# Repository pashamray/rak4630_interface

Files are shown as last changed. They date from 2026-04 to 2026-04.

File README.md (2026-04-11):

# RAK4630 Interface

An open-source hardware breakout / interface board for the **RAK4630** LoRa module (Nordic nRF52840 + Semtech SX1262), designed in KiCad 9.

## Gallery

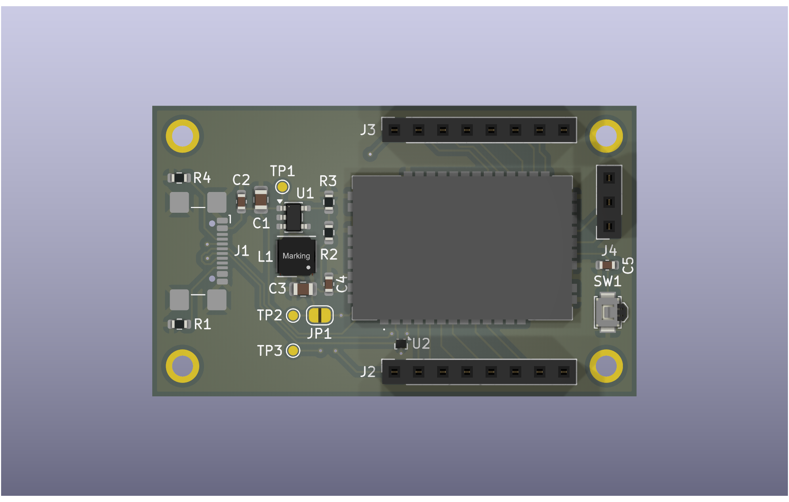
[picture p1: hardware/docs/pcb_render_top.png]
3D render top


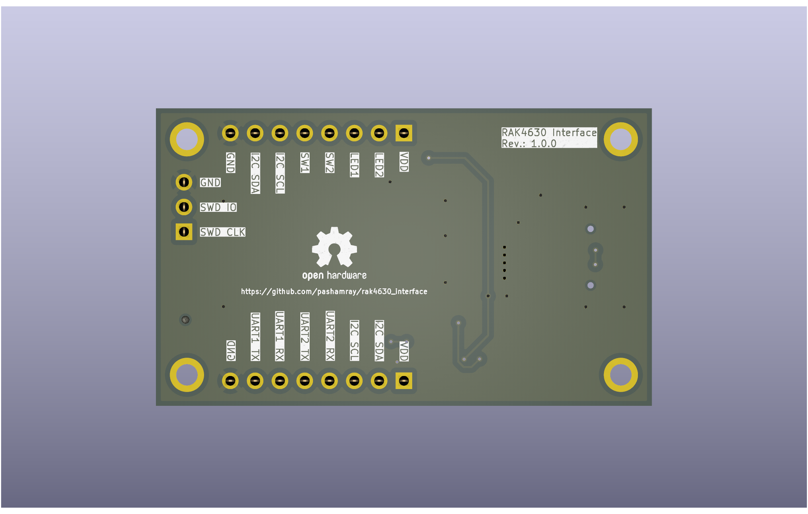
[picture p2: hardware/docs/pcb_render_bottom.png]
3D render bottom


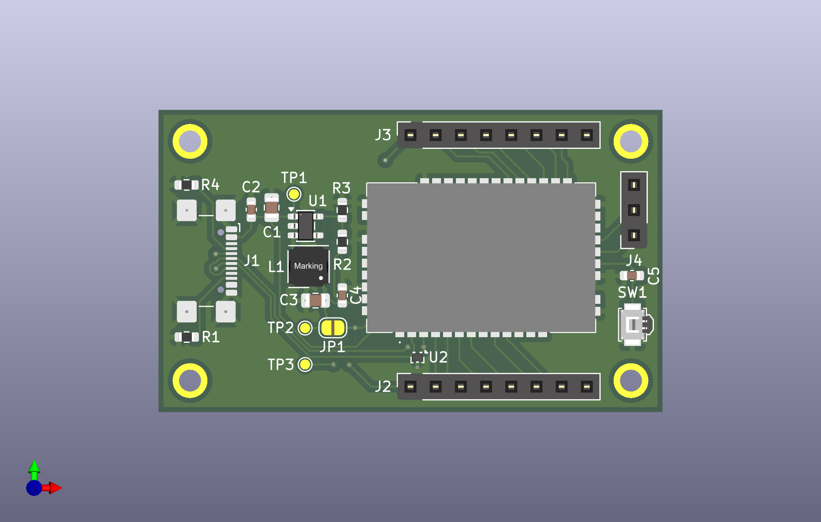
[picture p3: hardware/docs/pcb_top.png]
PCB top


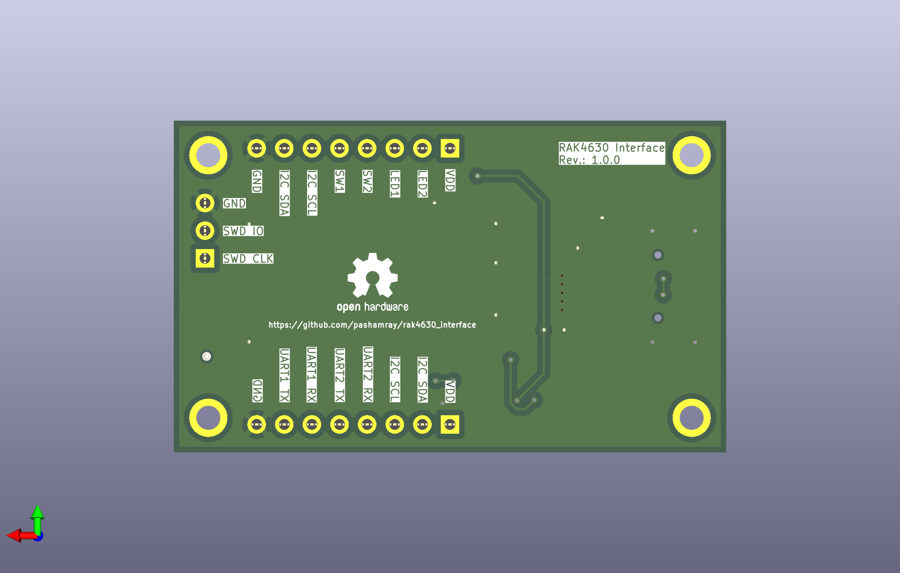
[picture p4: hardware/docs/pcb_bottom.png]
PCB bottom


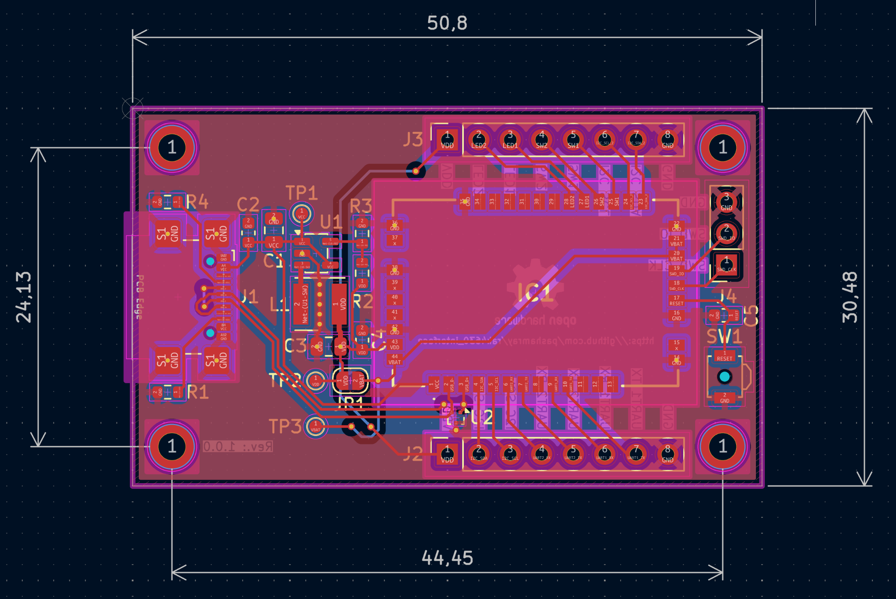
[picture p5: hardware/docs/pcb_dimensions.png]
PCB dimensions


## Overview

This board provides a minimal interface around the RAK4630 module, exposing its programming and I/O lines on a header and powering it from a USB-C port. It is intended as a development and flashing carrier for the RAK4630.

## Features

- **RAK4630 module** footprint (nRF52840 MCU + SX1262 LoRa radio)
- **USB-C 2.0 receptacle** for power and data
- **TPD2EUSB30** USB ESD protection
- **TLV62569DBV** step-down DC/DC converter for the 3.3 V rail
- **Reset push button**
- **Solder jumper** for power-rail / option configuration
- **8-pin breakout header** for GPIO / SWD / UART access
- **Test points** for key signals

## Repository layout

```
hardware/
├── kicad/      KiCad 9 project (schematic, PCB, project files)
├── gerber/     Manufacturing outputs (Gerbers + drill files)
└── libs/       Project-specific symbol/footprint/3D libraries (RAK4630)
```

## Manufacturing

Ready-to-fab Gerber and Excellon drill files are provided in `hardware/gerber/`. They follow the standard KiCad naming convention and can be uploaded as-is to most PCB fabrication houses.

## Opening the design

1. Install [KiCad 9](https://www.kicad.org/) or newer.
2. Open `hardware/kicad/rak4630_interface.kicad_pro`.

The RAK4630 symbol, footprint and 3D model are bundled under `hardware/libs/RAK4630/` and are referenced via the project library table — no global library setup is required.

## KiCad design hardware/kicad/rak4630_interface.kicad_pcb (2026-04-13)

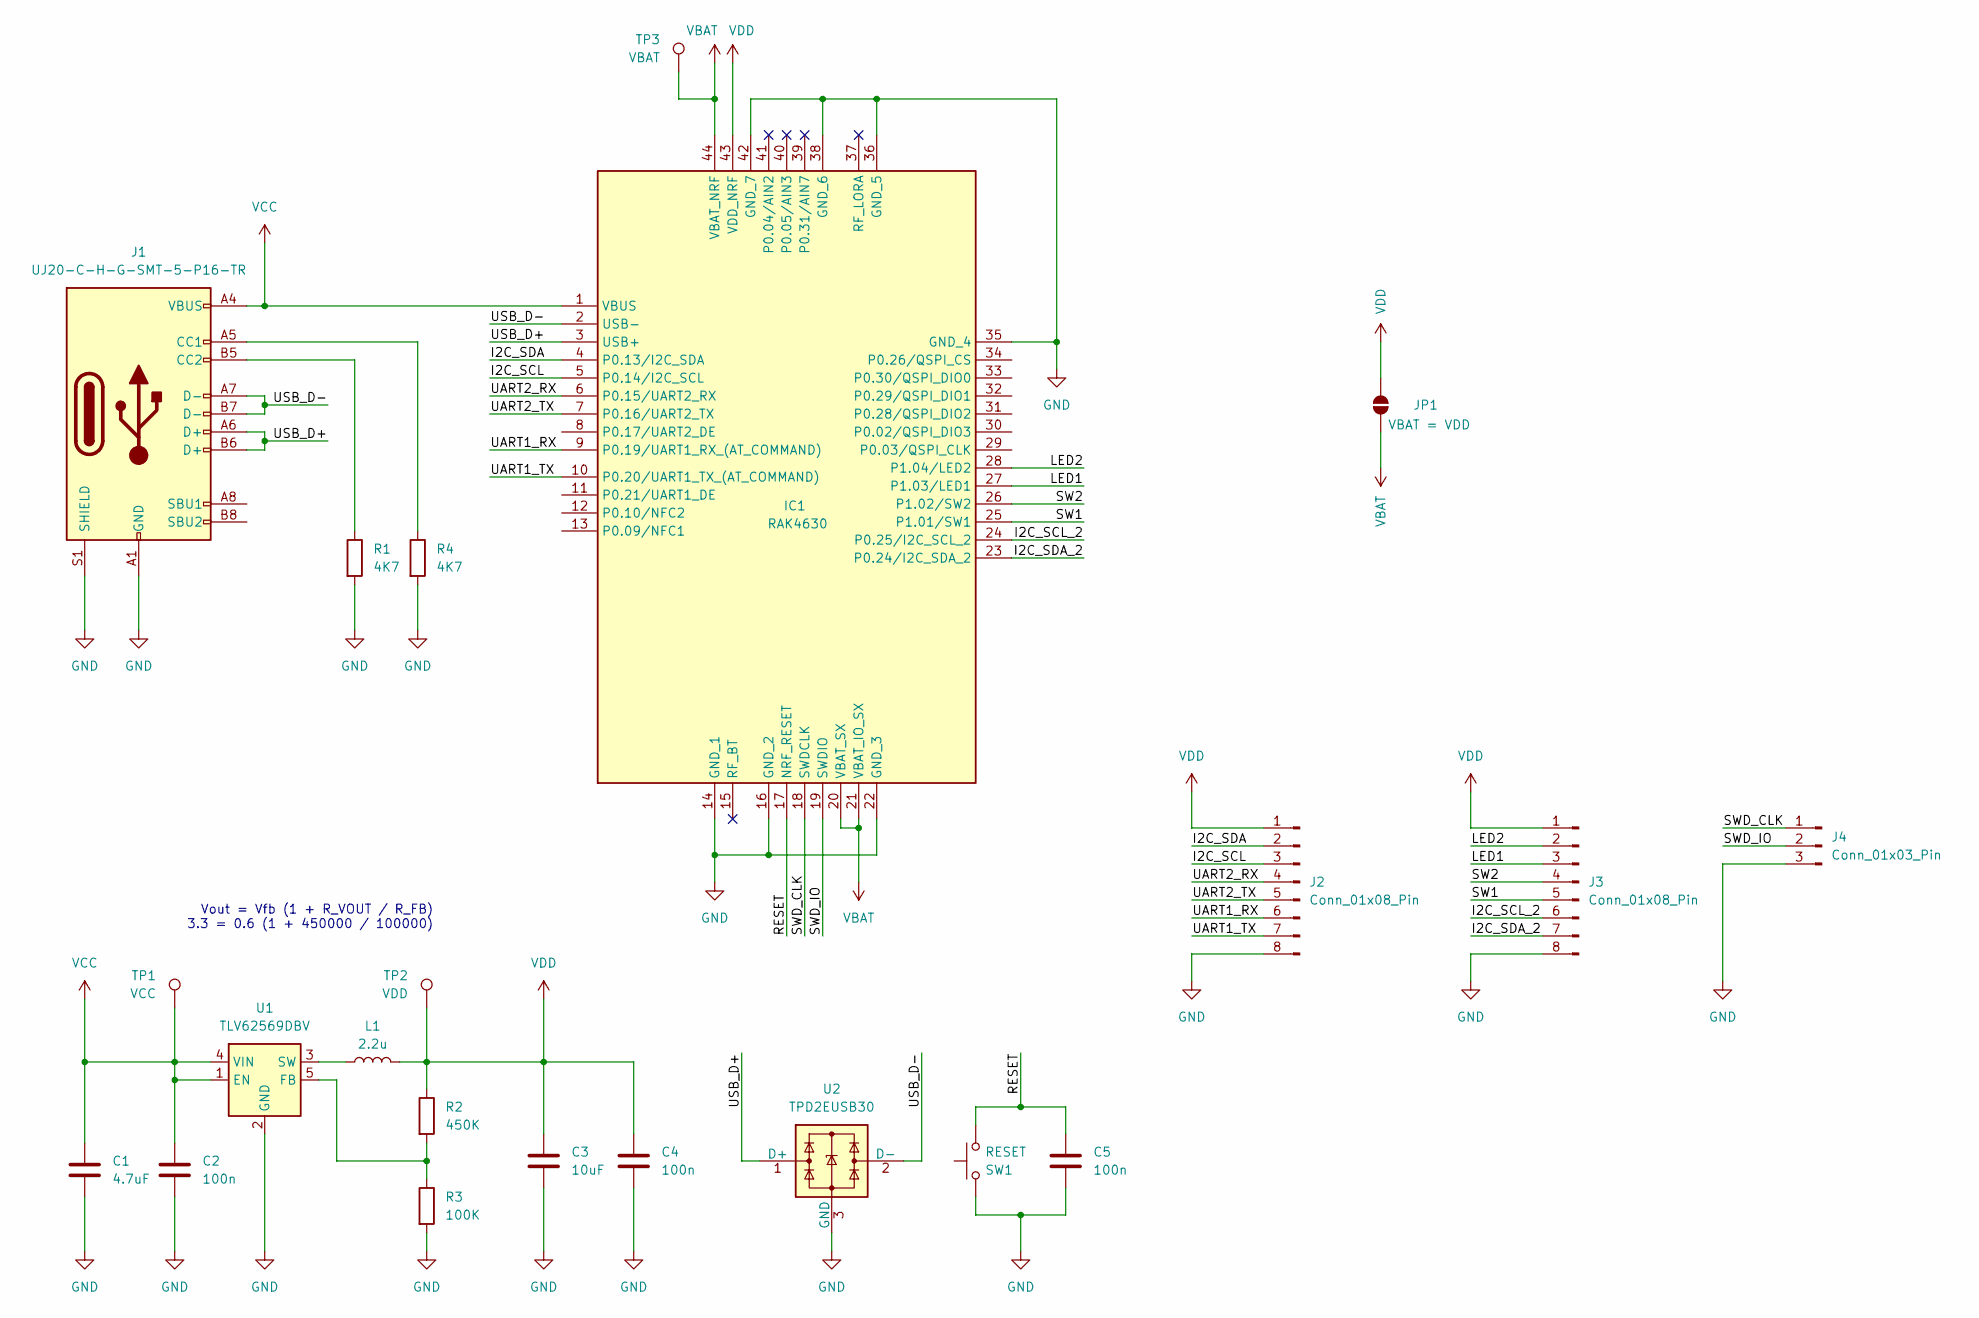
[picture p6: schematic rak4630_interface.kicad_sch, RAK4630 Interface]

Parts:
C1: 4.7uF; C_0805_2012Metric
C2, C4, C5: 100n; C_0603_1608Metric
C3: 10uF; C_0805_2012Metric
IC1: RAK4630; Manufacturer_Part_Number RAK4630
J1: UJ20-C-H-G-SMT-5-P16-TR; USB_C_Receptacle_GCT_USB4110
J2, J3: Conn_01x08_Pin; PinSocket_1x08_P2.54mm_Vertical
J4: Conn_01x03_Pin; PinSocket_1x03_P2.54mm_Vertical
JP1: VBAT = VDD; SolderJumper-2_P1.3mm_Open_RoundedPad1.0x1.5mm
L1: 2.2u; L_Wurth_WE-LQSH-4020
R1, R4: 4K7; R_0603_1608Metric
R2: 450K; R_0603_1608Metric
R3: 100K; R_0603_1608Metric
SW1: RESET; SW_SPST_B3U-3000P-B
TP1: VCC; TestPoint_Pad_D1.0mm
TP2: VDD; TestPoint_Pad_D1.0mm
TP3: VBAT; TestPoint_Pad_D1.0mm
U1: TLV62569DBV; SOT-23-5
U2: TPD2EUSB30; Texas_DRT-3

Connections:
/I2C_SCL: IC1.5 (P0.14/I2C_SCL), J2.3
/I2C_SCL_2: IC1.24 (P0.25/I2C_SCL_2), J3.6
/I2C_SDA: IC1.4 (P0.13/I2C_SDA), J2.2
/I2C_SDA_2: IC1.23 (P0.24/I2C_SDA_2), J3.7
/LED1: IC1.27 (P1.03/LED1), J3.3
/LED2: IC1.28 (P1.04/LED2), J3.2
/RESET: C5.1, IC1.17 (NRF_RESET), SW1.1
/SW1: IC1.25 (P1.01/SW1), J3.5
/SW2: IC1.26 (P1.02/SW2), J3.4
/SWD_CLK: IC1.18 (SWDCLK), J4.1
/SWD_IO: IC1.19 (SWDIO), J4.2
/UART1_RX: IC1.9 (P0.19/UART1_RX_(AT_COMMAND)), J2.6
/UART1_TX: IC1.10 (P0.20/UART1_TX_(AT_COMMAND)), J2.7
/UART2_RX: IC1.6 (P0.15/UART2_RX), J2.4
/UART2_TX: IC1.7 (P0.16/UART2_TX), J2.5
/USB_D+: IC1.3 (USB+), J1.A6 (D+), J1.B6 (D+), U2.1 (D+)
/USB_D-: IC1.2 (USB-), J1.A7 (D-), J1.B7 (D-), U2.2 (D-)
GND: C1.2, C2.2, C3.2, C4.2, C5.2, IC1.14 (GND_1), IC1.16 (GND_2), IC1.22 (GND_3), IC1.35 (GND_4), IC1.36 (GND_5), IC1.38 (GND_6), IC1.42 (GND_7), J1.A1 (GND), J1.A12 (GND), J1.B1 (GND), J1.B12 (GND), J1.S1 (SHIELD), J2.8, J3.8, J4.3, R1.2, R3.2, R4.2, SW1.2, U1.2 (GND), U2.3 (GND)
unnamed: J1.A5 (CC1), R4.1
unnamed: J1.B5 (CC2), R1.1
unnamed: R2.2, R3.1, U1.5 (FB)
unnamed: L1.2, U1.3 (SW)
VBAT: IC1.20 (VBAT_SX), IC1.21 (VBAT_IO_SX), IC1.44 (VBAT_NRF), JP1.2 (B), TP3.1
VCC: C1.1, C2.1, IC1.1 (VBUS), J1.A4 (VBUS), J1.A9 (VBUS), J1.B4 (VBUS), J1.B9 (VBUS), TP1.1, U1.1 (EN), U1.4 (VIN)
VDD: C3.1, C4.1, IC1.43 (VDD_NRF), J2.1, J3.1, JP1.1 (A), L1.1, R2.1, TP2.1

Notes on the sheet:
Vout = Vfb (1 + R_VOUT / R_FB) 3.3 = 0.6 (1 + 450000 / 100000)

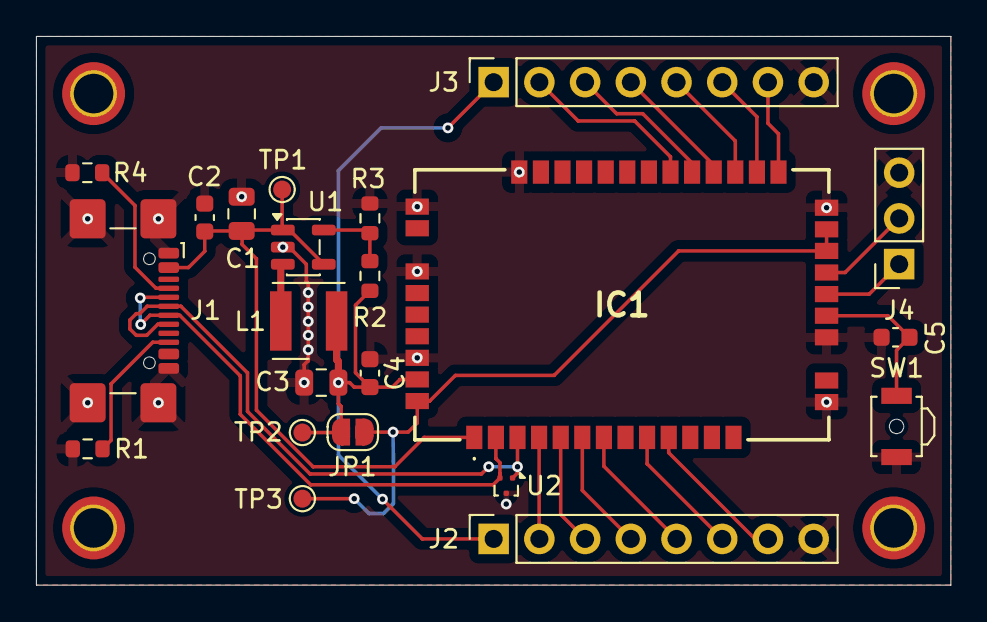
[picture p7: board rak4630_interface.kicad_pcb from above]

Board: 2 copper layers, 50.8 x 30.5 mm, 22 parts (0 on the bottom side), 25 nets.

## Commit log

2026-04-10 update pcb
    [rak4630_interface-B_Cu.gbr, rak4630_interface-B_Mask.gbr, rak4630_interface-B_Paste.gbr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]
2026-04-10 update annotations
    [rak4630_interface.kicad_sch]
